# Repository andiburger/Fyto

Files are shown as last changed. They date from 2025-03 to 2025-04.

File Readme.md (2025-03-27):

# Smart Plant Pot

Inspired by [Fyto Project](https://www.hackster.io/coderscafe/fyto-turn-your-plant-into-pet-1373d5#code)

## Hardware components
- Raspberry Pi Zero 2 W
- ADS1115 ADC Module 16Bit 4 channels for Raspberry Pi
- Soil Moisture Sensor Hygrometer Module V1.2
- DS18B20 digital temperature sensor
- LDR-Lichtsensor resistiv
- Power Distributor Terminal Block 2x12

## Wiring
### Complete wiring of smart pot.
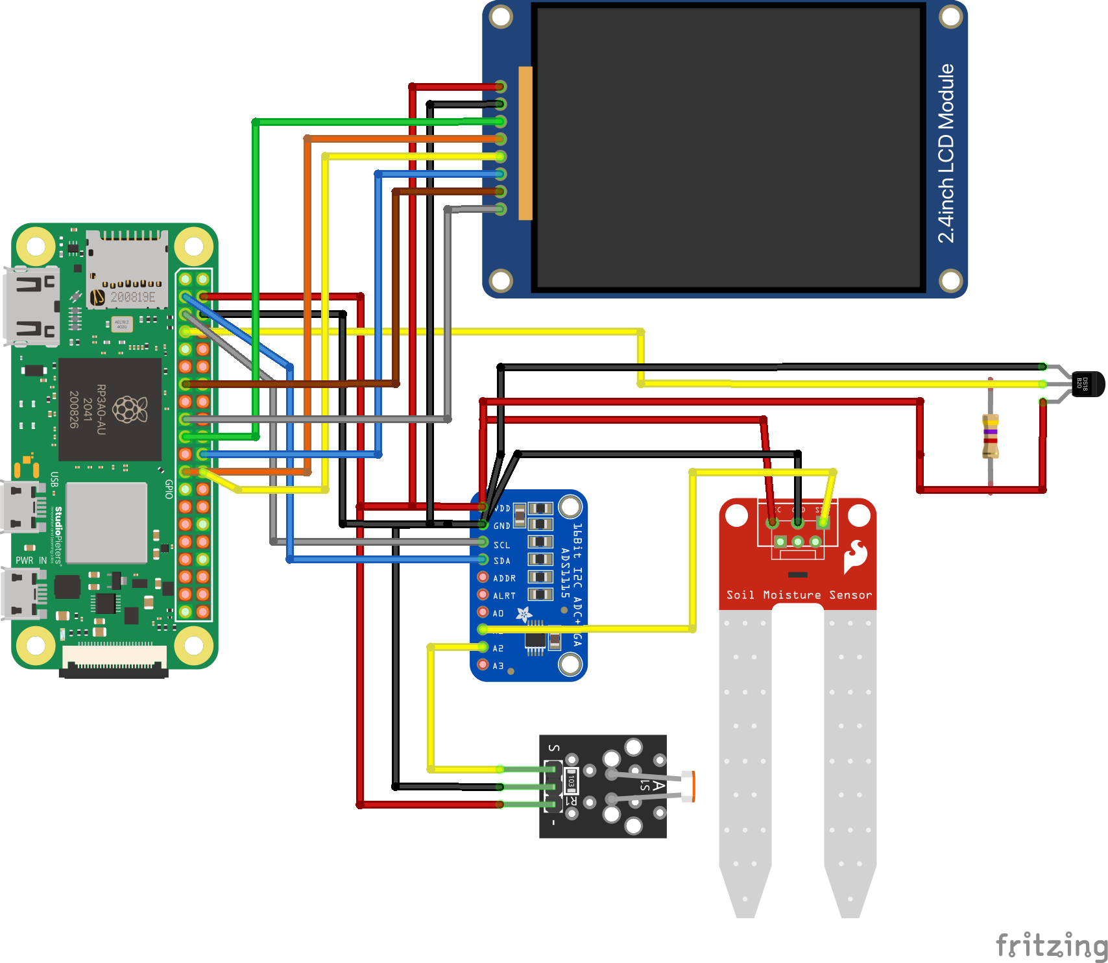
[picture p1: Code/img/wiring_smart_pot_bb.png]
Complete wiring with RPI Zero 2 W


### Wiring of the LCD display with RPI Zero 2 W.
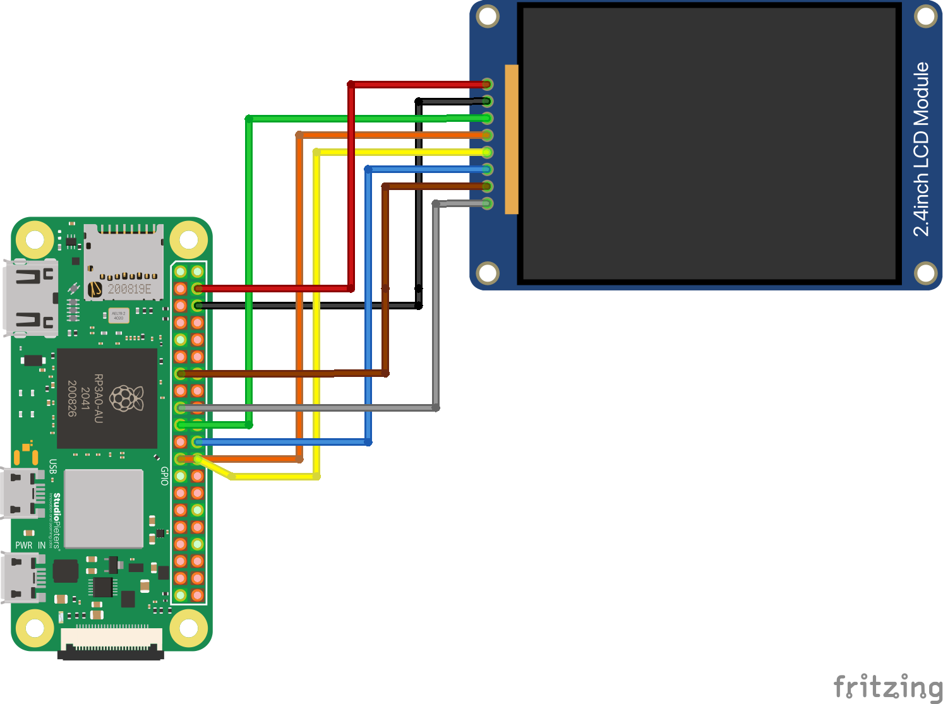
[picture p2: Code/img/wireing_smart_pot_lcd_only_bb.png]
Wiring of RPI Zero 2 with LCD Display


### Wiring of sensors with RPI Zero 2 W.
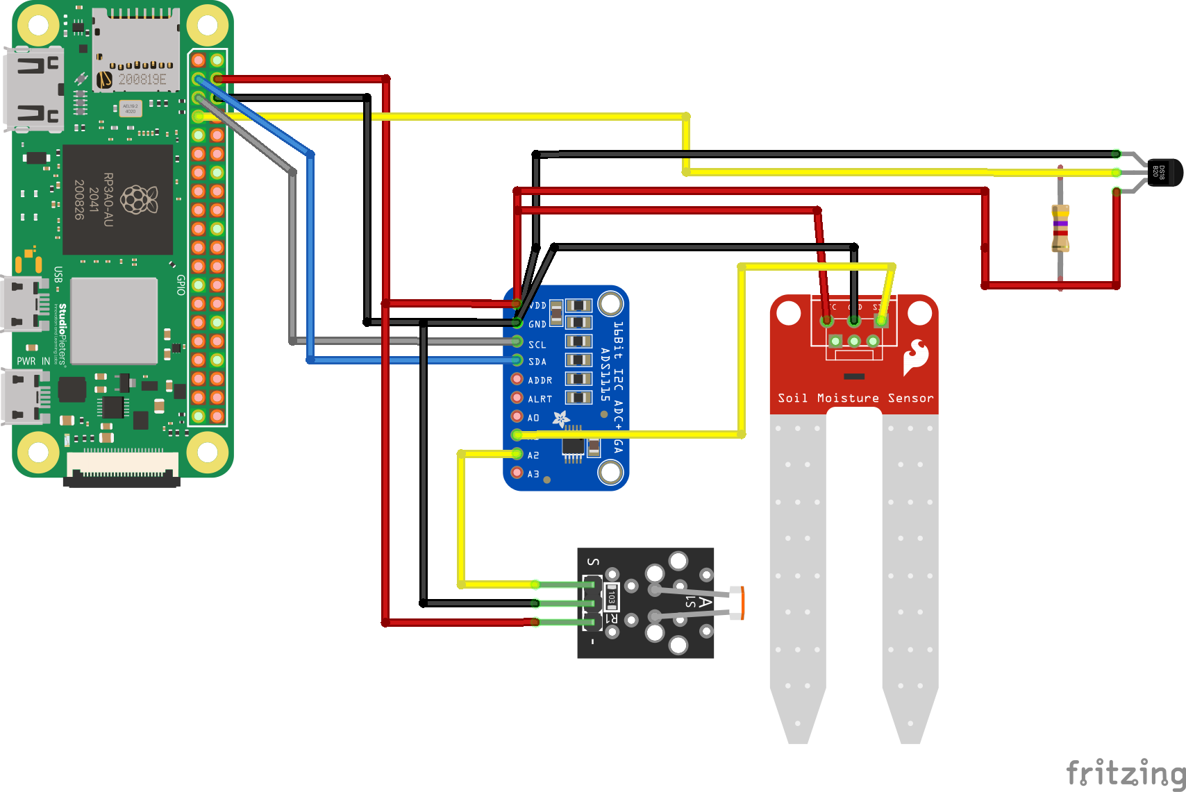
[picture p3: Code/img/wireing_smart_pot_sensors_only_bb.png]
Wiring of sensors with RPI Zero 2 W and ADS1115


## Installation & Setup

### Prerequisites
- Python 3.11 or later
- Virtual environment (recommended)
- MQTT server
- Dependencies from `requirements.txt`

### Using DS18B20 Temperature Sensor with Raspberry Pi Zero 2 W

This guide explains how to set up and read data from the **DS18B20** temperature sensor on a **Raspberry Pi Zero 2 W**.

### Wiring the DS18B20 Sensor

| DS18B20 Pin | Raspberry Pi GPIO |
|---|---|
| **VCC** (3.3V or 5V) | Pin 1 (3.3V) or Pin 2/4 (5V) |
| **GND** | Pin 6 (GND) |
| **DATA** | GPIO 4 (Pin 7) |

see wiring diagrams above.

🔹 **Important:**  
- A **4.7kΩ pull-up resistor** is required between **DATA** and **VCC**.

### Enabling 1-Wire Interface on Raspberry Pi

1. Enable the **1-Wire** interface in raspi-config.
```bash
sudo raspi-config
```
Choose Interfacing Options → 1-Wire → Enable.

2. Reboot.
```bash
sudo reboot
```

Alternatively you can manually activate the **1-Wire** interface

1. Load the **1-Wire** module.
```bash
sudo modprobe w1-gpio
sudo modprobe w1-therm
```

2. Add **1-Wire** module to /etc/modules to ensure it will reloaded on reboot.
```bash
echo "w1-gpio" | sudo tee -a /etc/modules
echo "w1-therm" | sudo tee -a /etc/modules
```

3. Reboot.
```bash
sudo reboot
```

4. Ensure the sensor is recognized correctly.
```bash
ls /sys/bus/w1/devices/
```
You should see a directory with a name like 28-xxxxxxxxxxxx.
If the sensor is not listed, check the wiring and the pull-up resistor.

### Using ADS1115 on the RPI Zero 2 W.

1. Enabling I²C on the Raspberry Pi

To use the ADS1115, you need to enable the I²C interface on your Raspberry Pi.

1. Open the Raspberry Pi configuration tool:
   ```bash
   sudo raspi-config
   ```
2. Navigate to **Interfacing Options** → **I2C** → **Enable**.
3. Exit the tool and reboot your Raspberry Pi:
   ```bash
   sudo reboot
   ```

2. Checking if the ADS1115 is Detected

After rebooting, check if the Raspberry Pi detects the **ADS1115**:

1. Install the I²C tools (if not already installed):
   ```bash
   sudo apt install -y i2c-tools
   ```
2. Scan for connected I²C devices:
   ```bash
   i2cdetect -y 1
   ```

**Expected Output (if `ADDR` is connected to GND, default address 0x48):**
```
     0  1  2  3  4  5  6  7  8  9  A  B  C  D  E  F
00:          -- -- -- -- -- -- -- -- -- -- -- -- --  
10: -- -- -- -- -- -- -- -- -- -- -- -- -- -- -- --  
20: -- -- -- -- -- -- -- -- -- -- -- -- -- -- -- --  
30: -- -- -- -- -- -- -- -- -- -- -- -- -- -- -- --  
40: -- -- -- -- -- -- -- -- 48 -- -- -- -- -- -- --  
```
If no address appears, check the **wiring** and ensure I²C is **enabled**.

### Installation
1. **Clone the repository:**
   ```sh
   git clone <repository-url>
   cd <repository-name>
   ```

2. **Create & activate a virtual environment:**
   ```sh
   python -m venv venv
   source venv/bin/activate  # macOS/Linux
   venv\Scripts\activate     # Windows
   ```

3. **Install dependencies:**
   ```sh
   pip install -r requirements.txt
   ```

### Calibrate sensors / verify sensors are running
```sh
python calibration.py
```
You should see every second a values for Moisture, Light Intensity and Temperature in the Terminal. Something like:
```bash
Moisture: 73
Light Intensity: 4567
Temperature: 23.45 °C
```
This could be used to verify the wiring is correct and the sensors measure plausible values.

## Usage

### **Start the Main Program**
The `main.py` script starts the configuration server and sensor system as subprocesses.
- **Configuration Server Port (`--port-cfg-server`)**: The port the config server runs on (default: `5000`).
- **Communication Port (`--port-com`)**: Manages communication between sensors and the main script (default: `5050`).

The `main.py` script also ensures proper shutdown by handling `KeyboardInterrupt` (Ctrl+C), stopping the server and sensor processes gracefully.

### Usage
Run the script using the following command:
```bash
python main.py --port-cfg-server 5000 --port-com 5050
```
You can also omit the parameters to use the default values.

### Shutdown Handling
If the script receives a `KeyboardInterrupt`, it will:
1. Log the shutdown process.
2. Terminate the Flask server (`cfg_server_process`).
3. Terminate the sensor script (`sensor_server_process`).
4. Close the socket server.
5. Exit gracefully.

### **Configure Smart Pot via Configuration Server**
Open a web browser and connect to the configuration server with the following address: `https://PI-ZERO-IP-ADDR:5000`

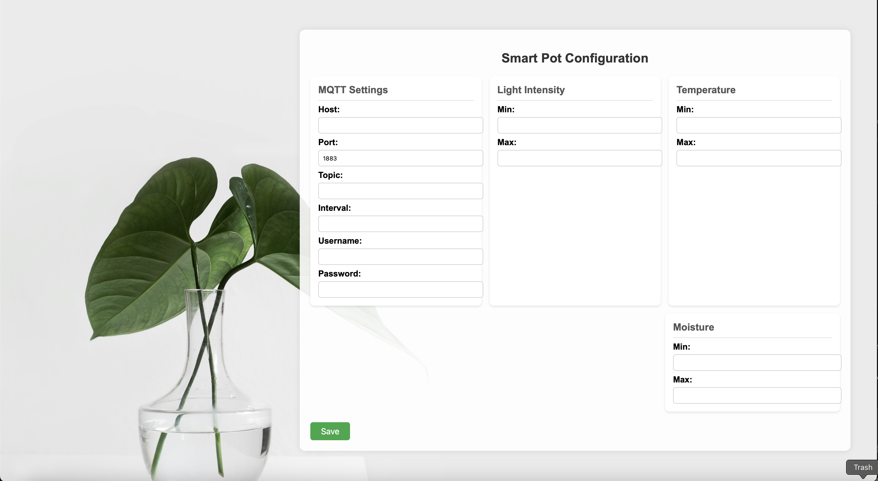
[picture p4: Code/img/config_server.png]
Screenshot of configuration server


Set the parameter as shown in the screenshot above. MQTT User and Password are optional.
The following parameter can be used as default for light intensity, temperature and moisture:
- Light intensity min: 0
- Light intensity max: 5000

- Temperature min: 18
- Temperature max: 30

- Moisture min: 10
- Moisture max: 130

Then press the button save.
You should now see values for Light, Temperature and Moisture published on the given topic on your MQTT server. This means your smart pot is up and running. Additionally the LCD display shows you the current state of your plant, visualized with some simleys.

## API Endpoints (config_server.py)
| Method  | Endpoint | Description |
|---|---|---|
| `GET` | `/config` | Retrieve configuration settings |
| `POST`  | `/config` | Set configuration settings |

### Configurable Parameters:
The following parameters can be set via the `/config` endpoint:
- `moisture` (int): The soil moisture level at which watering should be triggered.
- `temperature` (float): Maximum temperature before triggering an alert.
- `light` (int): Minimum required light intensity for the plant.

## Troubleshooting
- If you encounter a `Permission denied` error, try running the script with `sudo` or changing the port number.
- Ensure that `pip install -r requirements.txt` has been executed.

## License
This project is licensed under the MIT License.

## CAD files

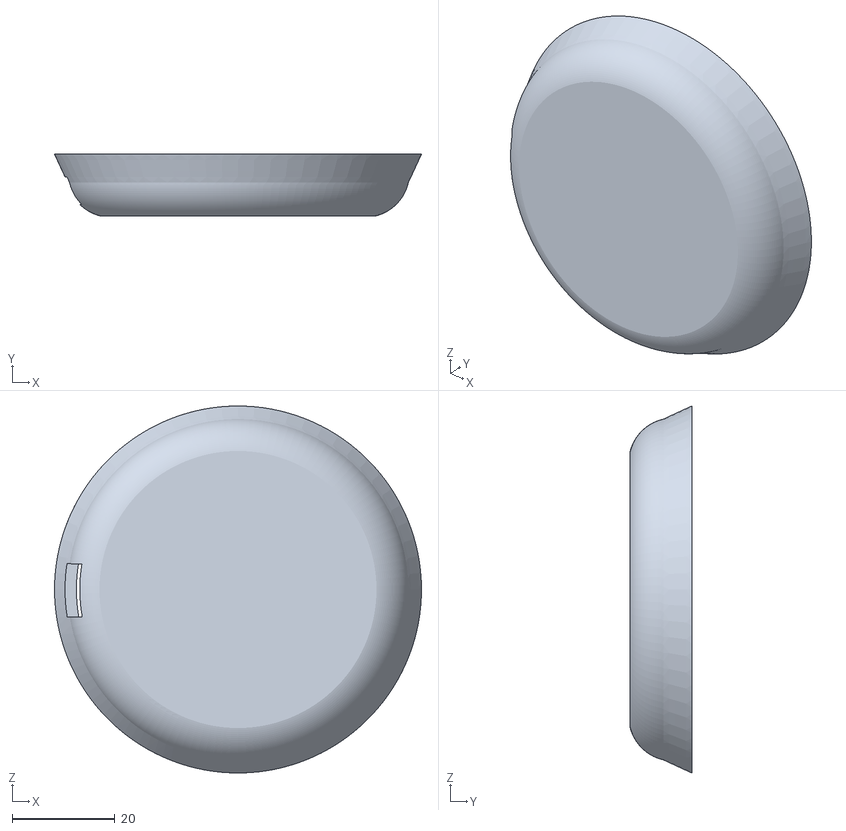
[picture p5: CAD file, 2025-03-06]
3D/base_part-Flower_Latest v16.stl
71.5 x 12.0 x 71.5

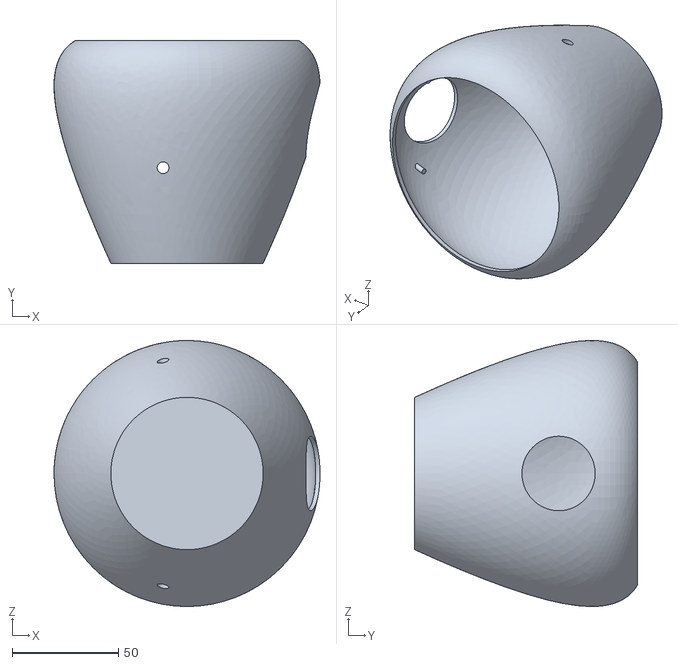
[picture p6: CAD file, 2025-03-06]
3D/outer_part.stl
125.0 x 104.7 x 125.0

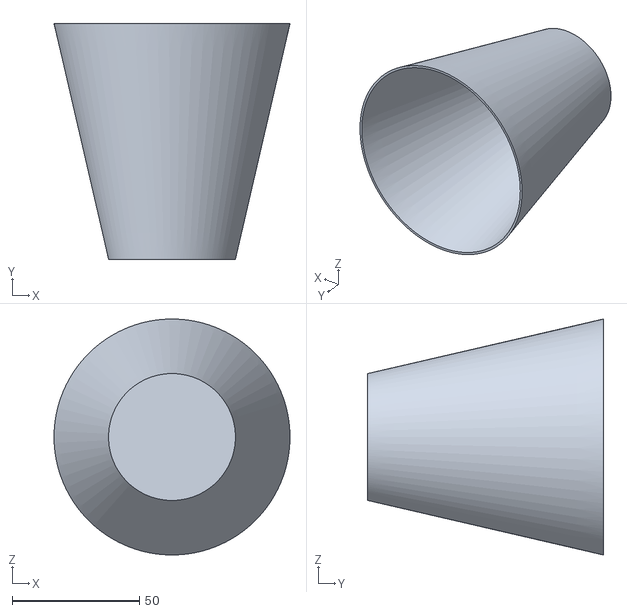
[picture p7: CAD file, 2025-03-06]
3D/inner_part-Flower_Latest v16Vase.stl
92.6 x 92.5 x 92.6

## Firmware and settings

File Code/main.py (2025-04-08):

import os
import sys 
import logging
import spidev as SPI # type: ignore
sys.path.append("..")
from lib import LCD_2inch
from PIL import Image,ImageDraw,ImageFont
import socket
import requests
import json
import subprocess
from threading import Thread
import time
import argparse
from threading import Thread


# path to sensors script
script_path = 'sensors.py'
# path to config server script
config_server_path = 'config_server'
# global variable to store config data
config_data = {}

cfg_server_process = None
sensor_server_process = None

server = None

# Raspberry Pi pin configuration:
RST = 27
DC = 25
BL = 18
bus = 0 
device = 0 
logging.basicConfig(level=logging.DEBUG)
directory = os.getcwd()
doInterrupt = 0
showOn = 0

show_thread = None

def is_venv():
    return sys.prefix != sys.base_prefix  

def is_virtualenv():
    return hasattr(sys, "real_prefix") 


last_emotion = None

def show_async(emotion):
    global show_thread, doInterrupt, last_emotion, showOn

    if emotion == last_emotion and showOn == 1:
        return

    if show_thread and show_thread.is_alive():
        doInterrupt = 1
        show_thread.join()

    doInterrupt = 0
    showOn = 1
    last_emotion = emotion
    show_thread = Thread(target=show, args=(emotion,))
    show_thread.start()

def show(emotion):

    global doInterrupt, showOn, disp
    logging.info("emotion:" + emotion)
    try:
        disp = LCD_2inch.LCD_2inch(spi=SPI.SpiDev(bus, device), spi_freq=90000000, rst=RST, dc=DC, bl=BL)
        disp.Init()  # Initialize library.

        if emotion == "black": # set display to black
            bg = Image.new("RGB", (disp.width, disp.height), "BLACK")
            disp.ShowImage(bg)
            disp.module_exit()
            logging.info("Display set to black")
            return

        bg = Image.new("RGB", (disp.width, disp.height), "BLACK")
        draw = ImageDraw.Draw(bg)
        
        for i in range(180):
            if doInterrupt == 1:
                logging.info("Interrupted during emotion display")
                doInterrupt = 0
                break
            else:
                with Image.open(directory + '/emotion/' + emotion + '/frame' + str(i) + '.png') as image:
                    image = image.rotate(180)
                    disp.ShowImage(image)
        
        showOn = 0
        disp.module_exit()
        logging.info("quit:")
    except IOError as e:
        logging.info(e)    
    except KeyboardInterrupt:
        disp.module_exit()
        logging.info("quit:")
        exit()

def main(args):
    global doInterrupt, showOn, cfg_server_process, sensor_server_process, server
    #Server For Data Reception
    server = socket.socket(socket.AF_INET, socket.SOCK_STREAM)
    server.bind(('0.0.0.0', args.port_com))
    server.listen(2)
    logging.info("Socket server started")
    # Start the Flask server detached
    logging.info("Starting Flask server")
    if is_venv():
        logging.info("Running in virtual environment")
        cfg_server_process = subprocess.Popen([sys.executable, "-m", "waitress", "--host=0.0.0.0", "--port="+str(args.port_cfg_server), "config_server:app"])
    elif is_virtualenv():
        logging.info("Running in virtual environment")
        cfg_server_process = subprocess.Popen([getattr(sys, "real_prefix", sys.prefix), "-m", "waitress", "--host=0.0.0.0", "--port="+str(args.port_cfg_server), "config_server:app"])
    else:
        logging.info("Running in global environment")
        cfg_server_process = subprocess.Popen(
        ["waitress-serve", "--host=0.0.0.0", "--port="+str(args.port_cfg_server), "config_server:app"],
        stdout=subprocess.PIPE,
        stderr=subprocess.PIPE
        )   
    logging.info("Flask server started")

    # Wait until the Flask server has a valid configuration
    url = 'http://127.0.0.1:'+str(args.port_cfg_server)+'/get_config'
    while True:
        try:
            response = requests.get(url)
            if response.status_code == 200:
                config_data = response.json()
                # Check if all required configs are available
                print(config_data)
                excluded_keys = {"MQTT Username", "MQTT Password"}  # optional keys MQTT Username and MQTT Password
                if all(value != "" or key in excluded_keys for key, value in config_data.items()):
                    logging.info("Valid configuration received")
                    break
            logging.info("Waiting for valid configuration...")
        except requests.exceptions.ConnectionError:
            logging.info("Waiting for Flask server to start...")
        time.sleep(1)

    logging.info("Valid configuration received")
    if type(config_data) is dict:
        config_data.update({"Port": args.port_com})
    # start sensors script detached
    logging.info("Starting sensors script")
    config_json = json.dumps(config_data) 
    if is_venv():
        logging.info("Running in virtual environment")
        sensor_server_process = subprocess.Popen([sys.executable, script_path, config_json])
    elif is_virtualenv():
        logging.info("Running in virtual environment")
        sensor_server_process = subprocess.Popen([getattr(sys, "real_prefix", sys.prefix), script_path, config_json])
    else:
        logging.info("Running in global environment")
        sensor_server_process = subprocess.Popen([sys.executable, script_path, config_json])
    # sensors script will send data to this server
    previousData = 'happy'
    show_async('happy')
    conn, addr = server.accept()
    conn.settimeout(0.1)
    while True:
        logging.info("waiting for data")
        try:
            data = ""
            data = conn.recv(1024).decode('utf-8')
            logging.info("data"+str(data))
            if '\n' in data:
                data = data.split('\n', 1)[0]
            print(data)
            if (previousData != data):
                print(data)
                doInterrupt = 1
                previousData = data
                show_async(data)
        except socket.timeout:
            if showOn!=1:
                show_async(previousData)
                

                
if __name__=='__main__':
    try:
        parser = argparse.ArgumentParser(description="Start the server with a specific port.")
        parser.add_argument("--port-cfg-server", type=int, default=5000, help="Port number to run the server on")
        parser.add_argument("--port-com", type=int, default=5050, help="Port number to run the communication between sensors and main script")
        args = parser.parse_args()
        main(args)
    except KeyboardInterrupt:
        logging.info("Exiting...")
        if cfg_server_process:
            logging.info("Terminating Flask server")
            cfg_server_process.terminate()
        if sensor_server_process:
            logging.info("Terminating sensors script")
            sensor_server_process.terminate()
        server.close()
        logging.info("Socket server closed")
        sys.exit(0)

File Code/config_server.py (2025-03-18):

from flask import Flask, request, jsonify, render_template

app = Flask(__name__)

# Configuration data
config_data = {
    "MQTT Host": "",
    "MQTT Port": "1883",
    "MQTT Topic": "",
    "MQTT Username": "",
    "MQTT Password": "",
    "Light Intensity min": "",
    "Light Intensity max": "",
    "Temperature min": "",
    "Temperature max": "",
    "Moisture min": "",
    "Moisture max": ""
}
# Configuration page
@app.route('/')
def index():
    return render_template('config.html', config=config_data)
# API to set configuration
@app.route('/set_config', methods=['POST'])
def set_config():
    global config_data
    config_data.update(request.form)
    return jsonify({"message": "Configuration saved successfully"})
# API to get configuration
@app.route('/get_config', methods=['GET'])
def get_config():
    return jsonify(config_data)

# Run the server
if __name__ == '__main__':
    app.run(debug=True)

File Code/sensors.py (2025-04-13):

import time
import socket
from paho.mqtt import client as mqtt_client
import random
import logging
import json
import sys

import RPi.GPIO as GPIO # type: ignore
from datetime import datetime
from logic.sun_logic import get_location, get_sun_times
from logic.mqtt_client import connect_mqtt, on_disconnect
from logic.sensor_read import Sensor
from logic.emotion import Emotion

# Setup logging
logging.basicConfig(level=logging.INFO)
_LOGGER = logging.getLogger(__name__)
# initialize Sensors
my_sensors = Sensor()


# sensor script receives config via sys.argv
_LOGGER.info(f"arguments: {sys.argv}")
cfg={}
cfg = json.loads(sys.argv[1])
_LOGGER.info(f"config: {cfg}")

emotion_logic = Emotion(cfg)

# constants for mqtt
broker = cfg['MQTT Host']#'192.168.178.160'
port = int(cfg['MQTT Port'])#1883
topic = cfg['MQTT Topic']#"smart_pot/data"
emotion_topic = topic + "/emotion"
loc_topic = topic + "/location"
try:
    update_interval = int(cfg['MQTT Update Interval'])#360
except KeyError:
    _LOGGER.warning("No update interval configured. Using default (360s)")
    update_interval = 360
client_id = f'smart_pot-{random.randint(0, 1000)}'
username = cfg['MQTT Username']#'YOUR_USERNAME'
password = cfg['MQTT Password']#'YOUR_PASSWORD'
FIRST_RECONNECT_DELAY = 1
RECONNECT_RATE = 2
MAX_RECONNECT_COUNT = 12
MAX_RECONNECT_DELAY = 60


def mqtt_result_logging(topic, MQTT_MSG, status):
    if status == 0:
        _LOGGER.info(f"Send `{MQTT_MSG}` to topic `{topic}`")
    else:      
        _LOGGER.error(f"Failed to send message to topic {topic}")

try:
    #Setup Client for communication
    try:
        client = socket.socket(socket.AF_INET, socket.SOCK_STREAM)
        client.connect(('0.0.0.0', int(cfg['Port'])))
    except Exception as e:
        _LOGGER.error(f"Could not connect to display socket: {e}")
        raise
    #Connect to MQTT
    mqtt_client = connect_mqtt(broker=broker, port=port, client_id=client_id, username=username, password=password)
    mqtt_client.on_disconnect = on_disconnect
    mqtt_client.loop_start()

    # location info
    city = get_location(cfg['Location'])#"Berlin"
    MQTT_MSG = json.dumps({"location": city.name})
    result = mqtt_client.publish(loc_topic, MQTT_MSG)
    status = result[0]
    mqtt_result_logging(loc_topic, MQTT_MSG, status)
    MQTT_MSG = ""
    last_execution_time = time.time()
    last_sun_calc_date = datetime.now().date()
    sunrise, sunset = get_sun_times(city=city)
    last_sent_state = None
    while True:
        now = datetime.now()
        # Check if the current date is different from the last calculated date
        if now.date() != last_sun_calc_date:
            sunrise, sunset = get_sun_times(city=city)
            last_sun_calc_date = now.date()
            _LOGGER.info(f"Recalculated sunrise/sunset for {last_sun_calc_date}")

        is_daytime = sunrise <= now.time() <= sunset

        if is_daytime:
            if last_sent_state == "black":
                Temperature, LDR_Percent, Moisture_Percent = my_sensors.read_sensor_data()
                emotion = emotion_logic.get_current_emotion(Temperature, LDR_Percent, Moisture_Percent)
                if emotion != last_sent_state:
                    client.send(bytes(f"{emotion}\n", 'utf-8'))
                    last_sent_state = emotion
                _LOGGER.info("Daylight resumed. Sending default emotion.")
        else:
            client.send(bytes('black\n', 'utf-8'))
            last_sent_state = "black"
            time.sleep(1)
            continue # Skip the rest of the loop if it's nighttime
        _LOGGER.info(f"Now: {now.time()}, Sunrise: {sunrise}, Sunset: {sunset}")
        # Read the specified ADC channels using the previously set gain value.
        Temperature, LDR_Percent, Moisture_Percent = my_sensors.read_sensor_data()
        emotion = emotion_logic.get_current_emotion(Temperature, LDR_Percent, Moisture_Percent) # get current emotion
        # Check if the emotion has changed
        if emotion != last_sent_state:
            _LOGGER.info(f"Sending {emotion}")
            client.send(bytes(f"{emotion}\n", 'utf-8'))
            last_sent_state = emotion
            MQTT_MSG=json.dumps({"emotion": emotion})
            result = mqtt_client.publish(emotion_topic, MQTT_MSG)
            status = result[0]
            mqtt_result_logging(topic, MQTT_MSG, status)
            MQTT_MSG = ""
        current_time = time.time()
        if current_time - last_execution_time >= update_interval:
            MQTT_MSG=json.dumps({"Temperature":Temperature,"Light Intensity":LDR_Percent,"Moisture %":Moisture_Percent})
            #send only every 360 seconds
            result = mqtt_client.publish(topic, MQTT_MSG)
            status = result[0]
            mqtt_result_logging(topic, MQTT_MSG, status)
            MQTT_MSG = ""
            last_execution_time = current_time
        time.sleep(1)
except KeyboardInterrupt:
    _LOGGER.info("Script interrupted by user (Ctrl+C). Cleaning up...")

except Exception as e:
    _LOGGER.exception(f"Unexpected error: {e}")
finally:
    try:
        mqtt_client.loop_stop()
        mqtt_client.disconnect()
    except Exception as e:
        _LOGGER.warning(f"MQTT cleanup failed: {e}")
    try:
        client.close()
    except Exception as e:
        _LOGGER.warning(f"Socket cleanup failed: {e}")
    try:
        GPIO.cleanup()
    except Exception as e:
        _LOGGER.warning(f"GPIO cleanup failed: {e}")
    _LOGGER.info("Cleanup done. Exiting.") 

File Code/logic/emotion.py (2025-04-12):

class Emotion:
    """
    Emotion class to determine the current emotion of the plant based on environmental conditions.
    The class uses a scoring system to prioritize emotions based on temperature, light intensity, and moisture levels.
    The emotions are:
    - freeze: Critically cold
    - hot: Critically hot
    - thirsty: Low soil moisture
    - hydrated: Very moist soil
    - sleepy: Low light conditions
    - happy: Everything is fine (default if no issues)
    """

    def __init__(self, cfg):
        """ Initialize the Emotion class with configuration parameters.
        Args:
            cfg (dict): Configuration parameters for the emotion class.
        """
        # min max values
        self.LDR_Percent_min = int(cfg['Light Intensity min'])#20
        self.LDR_Percent_max = int(cfg['Light Intensity max'])#20
        self.Temperature_min = int(cfg['Temperature min'])#22
        self.Temperature_max = int(cfg['Temperature max'])#30
        self.Moisture_min = int(cfg['Moisture min'])#10
        self.Moisture_max = int(cfg['Moisture max'])#90
        return
    
    def get_current_emotion(self, temperature, ldr_percent, moisture_percent):
        """Determine the current emotion based on temperature, light intensity, and moisture level.
        Args:
            temperature (float): The current temperature.
            ldr_percent (float): The current light intensity as a percentage.
            moisture_percent (float): The current moisture level as a percentage.
        Returns:
            str: The current emotion of the plant.
        """
        # Priority-based emotion scoring system:
        #
        # | Emotion   | Meaning                    | Score |
        # |-----------|----------------------------|-------|
        # | freeze    | Critically cold            |   3   |
        # | hot       | Critically hot             |   3   |
        # | thirsty   | Low soil moisture          |   2   |
        # | hydrated  | Very moist soil            |   2   |
        # | sleepy    | Low light conditions       |   1   |
        # | happy     | Everything is fine         |   1   (default if no issues)
        #
        # Higher score = higher priority when multiple conditions match.
        # This ensures that more critical plant states are prioritized.
        scores = {
            "freeze": 0,
            "hot": 0,
            "thirsty": 0,
            "hydrated": 0,
            "sleepy": 0,
            "happy": 0,
        }
        # Check conditions and assign scores
        if temperature < self.Temperature_min:
            scores["freeze"] += 3
        elif temperature > self.Temperature_max:
            scores["hot"] += 3

        if moisture_percent < self.Moisture_min:
            scores["thirsty"] += 2
        elif moisture_percent > self.Moisture_max:
            scores["hydrated"] += 2

        if ldr_percent < self.LDR_Percent_min:
            scores["sleepy"] += 1

        if all(value == 0 for value in scores.values()):
            scores["happy"] = 1  # Standard

        # Determine the emotion with the highest score
        emotion = max(scores, key=scores.get)
        return emotion

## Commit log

2025-03-06 added stl files
    [base_part-Flower_Latest v16.stl, inner_part-Flower_Latest v16Vase.stl, outer_part.stl]
2025-03-07 added config server for smart pot; added mqtt client to publish sensor values
2025-03-15 sensor configuration changed
2025-03-15 calibration script changed to different input channels
2025-03-15 fix small error in calling waitress server
    [main.py]
2025-03-15 fix issue with optional keys in config
    [main.py]
2025-03-15 fix issue with json
    [main.py]
2025-03-15 add logging to sensors script
2025-03-15 fix issue with subprocess
    [main.py]
2025-03-15 fix string / int issue
    [sensors.py]
2025-03-15 small modifications in sending emotions via sockets
2025-03-23 fix issue in calibration script
    [calibration.py]
2025-03-23 fix temperature value issue
    [calibration.py]
2025-03-24 add calibration for digital temp sensor
2025-03-24 fixed issue with update interval
    [sensors.py]
2025-03-24 start documentation
    [wireing_smart_pot.fzz]
2025-03-25 adding more details to documentation
    [wireing_smart_pot_lcd_only.fzz, wireing_smart_pot_sensors_only.fzz]
2025-03-26 add code to control backlight, switches on at day, switches off at night
2025-03-27 fix typo in html cfg
    [sensors.py]
2025-03-27 fix issue of sunrise cond
    [sensors.py]
2025-03-27 add code to configure ports for flask and com server between sensors and main script
2025-03-29 fix issue in LDR
    [sensors.py]
2025-03-29 fix bug in main call
    [main.py]
2025-03-29 fix concatenation error in server call
    [main.py]
2025-03-29 fix mqtt publish call
    [sensors.py]
2025-04-06 fix bug in mqtt publish
    [sensors.py]
2025-04-07 test for fixing freeze stucked issue
    [main.py, sensors.py]
2025-04-08 fix bug in mqtt client connect
    [mqtt_client.py, sensors.py]
2025-04-08 fix issue in visualization
    [main.py]
2025-04-08 fix threading issue
2025-04-08 fix issue in daylight calc
    [sensors.py]
2025-04-08 fix time zone issue
    [sun_logic.py]
2025-04-08 small fix to reduce cpu load at night
    [sensors.py]
2025-04-10 fix issue that display remains dark after night
    [sensors.py]
2025-04-12 some fixes, for more robust code
    [sensors.py]
2025-04-12 modularize code further. emotion and sensor handling now in separate modules
